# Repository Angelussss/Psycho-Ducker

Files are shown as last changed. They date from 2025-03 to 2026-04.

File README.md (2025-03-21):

# Psycho Ducker

Welcome to the Psycho Ducker, a 75% exploded keyboard project! This is a hot-swappable, compact, and efficient keyboard. Below, you'll find all the details you need to build and understand this project.

## Layout

The keyboard features a 75% exploded layout, offering a balance between functionality and compactness. The exploded design separates key clusters for a modern aesthetic and improved usability.

## Components

### Essentials

-   **MCU:** STM32F072CBT6.
    
-   **Switches:** Cherry MX style (supports both 3-pin and 5-pin switches).
    
-   **Keycaps:** Standard keycap set compatible with the Cherry MX stem.
    
-   **Diodes:** SOD-123.
    
-   **Hot-swap sockets:** Kailh are recommended.

### Optionals

-   **M2 screws** (to secure the PCB to the case or standoffs).
    
-   **M2 standoffs** (for added stability between the PCB and case).
    
-   **Stabilizers** (PCB-mounted, required for larger keys like the spacebar, enter, and shift).

## Required Tools

-   **Soldering iron**: Required for soldering pretty much the whole project.

- **heatgun**: Heavily hinted for soldering the micro. with a basic soldering iron is very hard.
    
-   **USB cable**: Required for connecting the keyboard to your computer. The PCB uses a usb type-C connector. Be sure to have at least one usable!

## Assembly Requirements

To assemble this keyboard, you'll need medium tin soldering skills, particularly for the micro.

## Notes

-   This keyboard's PCB is designed for hot-swapping switches, making possible to change the switches without de-soldering and re-soldering.
    
-   Firmware is powered by [QMK](https://qmk.fm/), a powerful and customizable open-source keyboard firmware.
    
-   This design has been tested thoroughly and functions reliably. However, as with any DIY project, minor adjustments may be needed based on your specific components.
    
-   Feel free to use this design for personal projects, but please do not edit or misuse it.
    
-in this design there are several types of cases you might wanna use. you can find the different materials and files in the "case" folder. The case is not necessary and is hands down the hardest part as it uses specific and expensive machinery, 

## Photos

-   **Finished Build:** ![fnished keyboard photo]
    
-   **Render:** ![pcb render] (https://github.com/Angelussss/Psycho-Ducker/blob/main/images/pcb_render.png)

## Contact

For any questions, feedback, or assistance, feel free to reach out via Telegram: @AngelusPSPS.

Thank you for exploring this project! Happy building and typing!

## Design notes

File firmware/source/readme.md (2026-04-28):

# psycho_ducker

![psycho_ducker]

*A 75% exploded keyboard*

* Keyboard Maintainer: [Angelo Perotti](https://github.com/Angelussss)
* Hardware Supported: psycho_ducker
* Hardware Availability: this project is opensource, you can build your own!

Make example for this keyboard (after setting up your build environment):

    make psycho_ducker:default

Flashing example for this keyboard:

    make psycho_ducker:default:flash

See the [build environment setup](https://docs.qmk.fm/#/getting_started_build_tools) and the [make instructions](https://docs.qmk.fm/#/getting_started_make_guide) for more information. Brand new to QMK? Start with our [Complete Newbs Guide](https://docs.qmk.fm/#/newbs).

## Bootloader

Enter the bootloader in 2 ways:

* **Physical reset button**: Briefly press the button on the top right of the PCB on boot 
* **Keycode in layout**: Press the key mapped to `QK_BOOT` if it is available

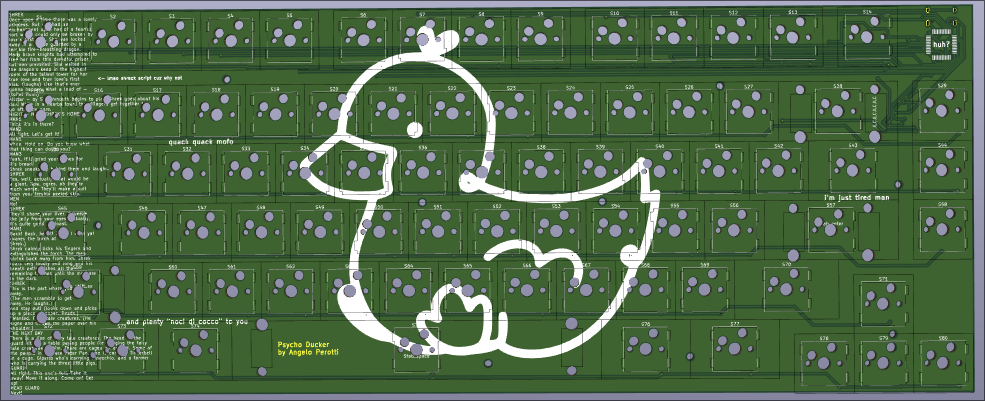
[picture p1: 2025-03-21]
images/pcb_render.png

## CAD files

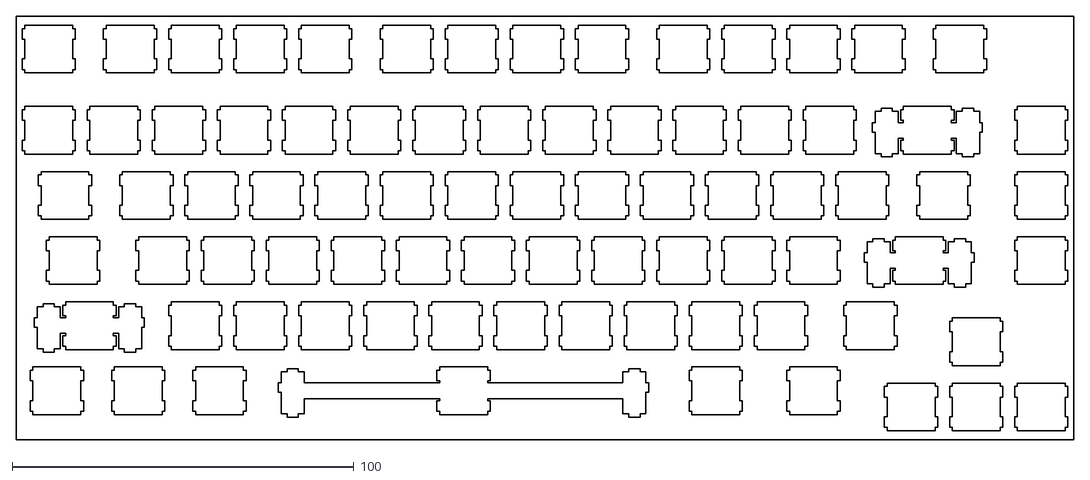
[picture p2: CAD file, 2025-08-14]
stuff/plate.dxf
309.6 x 123.8

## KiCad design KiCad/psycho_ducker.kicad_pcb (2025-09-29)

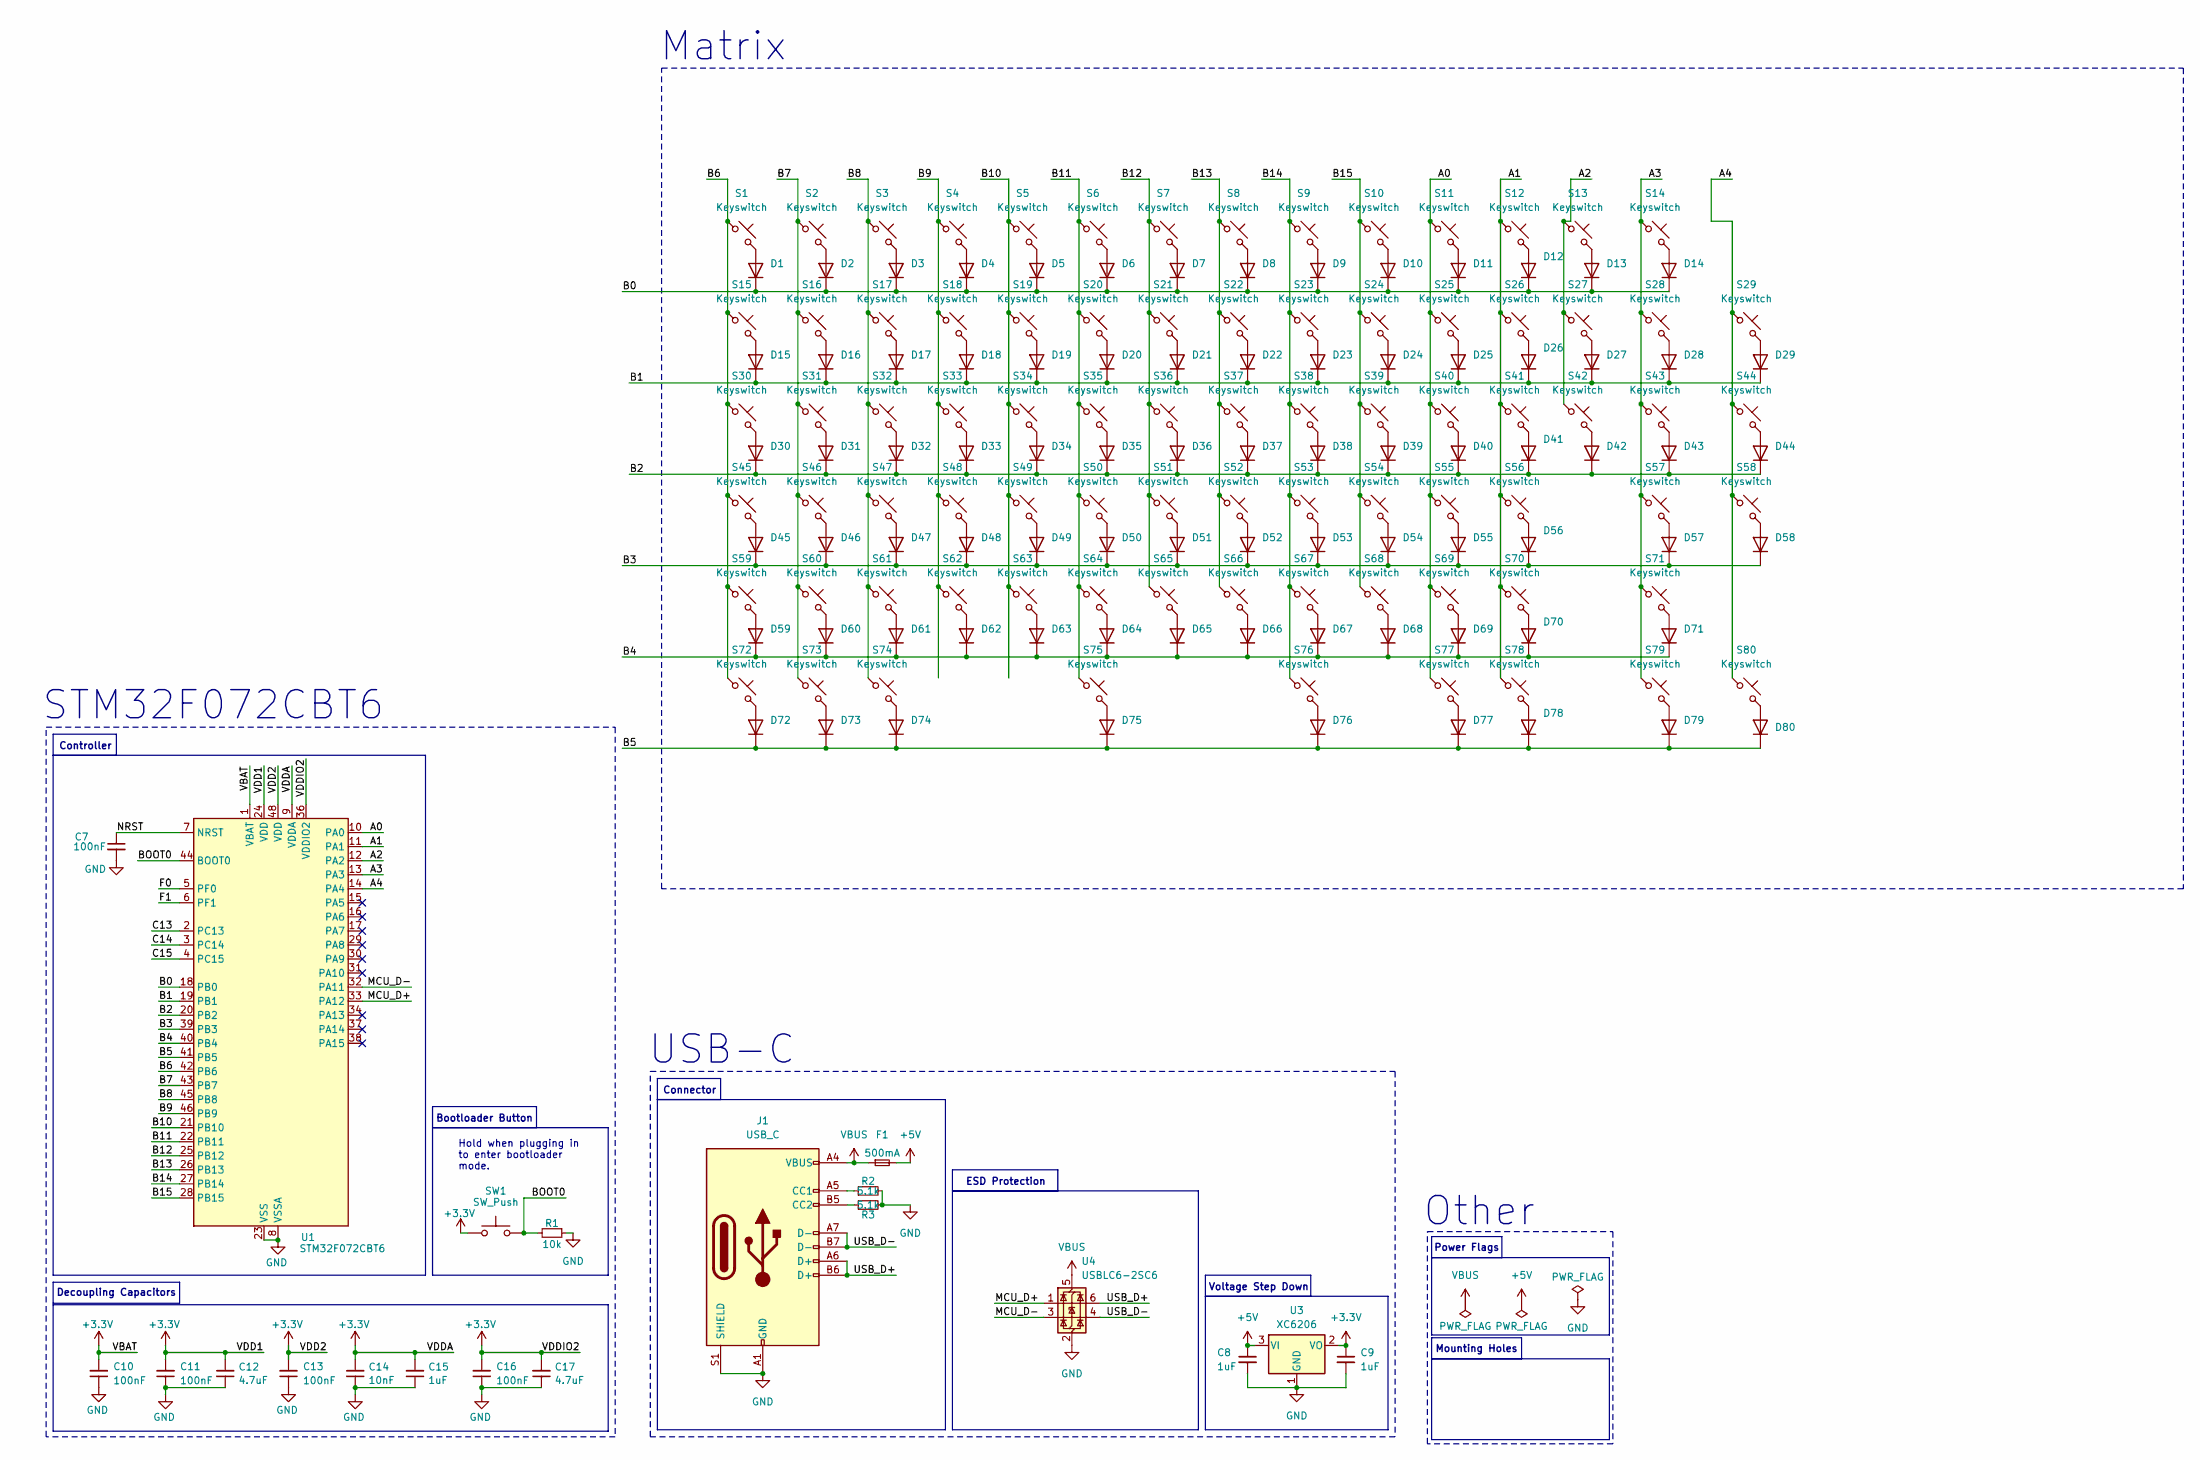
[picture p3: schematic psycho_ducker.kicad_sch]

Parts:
C7: 100nF; Capacitor_0402; LCSC C307331
C8, C9: 1uF; Capacitor_0402; LCSC C52923
C10, C11, C13, C16: 100nF; Capacitor_0402; MPN CL05B104KB54PNC; LCSC C307331
C12, C17: 4.7uF; Capacitor_0402; MPN CL05A475MP5NRNC; LCSC C23733
C14: 10nF; Capacitor_0402; MPN CL05B103KB5NNNC; LCSC C15195
C15: 1uF; Capacitor_0402; MPN CL05A105KA5NQNC; LCSC C52923
D1, D2, D3, D4, D5, D6, D7, D8, D9, D10, D11, D12, D13, D14, D15, D16, D17, D18, D19, D20, D21, D22, D23, D24, D25, D26, D27, D28, D29, D30, D31, D32, D33, D34, D35, D36, D37, D38, D39, D40, D41, D42, D43, D44, D45, D46, D47, D48, D49, D50, D51, D52, D53, D54, D55, D56, D57, D58, D59, D60, D61, D62, D63, D64, D65, D66, D67, D68, D69, D70, D71, D72, D73, D74, D75, D76, D77, D78, D79, D80: Diode; Diode_SOD-123
F1: 500mA; Fuse_0603; LCSC C210357
J1: USB_C; USB_C_HRO_TYPE-C-31-M-12; LCSC C165948
R1: 10k; R_0402_1005Metric; LCSC C25744
R2, R3: 5.1k; R_0402_1005Metric; LCSC C25905
S1, S2, S3, S4, S5, S6, S7, S8, S9, S10, S11, S12, S13, S14, S15, S16, S17, S18, S19, S20, S21, S22, S23, S24, S25, S26, S27, S29, S31, S32, S33, S34, S35, S36, S37, S38, S39, S40, S41, S42, S44, S46, S47, S48, S49, S50, S51, S52, S53, S54, S55, S56, S58, S60, S61, S62, S63, S64, S65, S66, S67, S68, S69, S71, S78, S79, S80: Keyswitch; Hotswap_MX_1.00u
S28: Keyswitch; Hotswap_MX_2.00u
S30, S43, S76, S77: Keyswitch; Hotswap_MX_1.50u
S45, S70: Keyswitch; Hotswap_MX_1.75u
S57, S59: Keyswitch; Hotswap_MX_2.25u
S72, S73, S74: Keyswitch; Hotswap_MX_1.25u
S75: Keyswitch; Hotswap_MX_6.25u
SW1: SW_Push; Button_TL3342; LCSC C115351
U1: STM32F072CBT6; Package_LQFP-48_7x7mm_P0.5; LCSC C81720
U3: XC6206; Voltage_SOT-23; LCSC C5446
U4: USBLC6-2SC6; ESD_SOT-23-6; LCSC C2827654

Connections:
+3.3V: C9.1, C10.2, C11.2, C12.2, C13.2, C14.2, C15.2, C16.2, C17.2, SW1.1, U1.1 (VBAT), U1.9 (VDDA), U1.24 (VDD), U1.36 (VDDIO2), U1.48 (VDD), U3.2 (VO)
+5V: C8.1, F1.2, U3.3 (VI)
/A0: S11.1, S25.1, S40.1, S55.1, S69.1, S77.1, U1.10 (PA0)
/A1: S12.1, S26.1, S41.1, S56.1, S70.1, S78.1, U1.11 (PA1)
/A2: S13.1, S27.1, S42.1, U1.12 (PA2)
/A3: S14.1, S28.1, S43.1, S57.1, S71.1, S79.1, U1.13 (PA3)
/A4: S29.1, S44.1, S58.1, S80.1, U1.14 (PA4)
/A5: U1.15 (PA5)
/A6: U1.16 (PA6)
/A7: U1.17 (PA7)
/A8: U1.29 (PA8)
/A9: U1.30 (PA9)
/A10: U1.31 (PA10)
/A13: U1.34 (PA13)
/A14: U1.37 (PA14)
/A15: U1.38 (PA15)
/B0: D1.1 (K), D2.1 (K), D3.1 (K), D4.1 (K), D5.1 (K), D6.1 (K), D7.1 (K), D8.1 (K), D9.1 (K), D10.1 (K), D11.1 (K), D12.1 (K), D13.1 (K), D14.1 (K), U1.18 (PB0)
/B1: D15.1 (K), D16.1 (K), D17.1 (K), D18.1 (K), D19.1 (K), D20.1 (K), D21.1 (K), D22.1 (K), D23.1 (K), D24.1 (K), D25.1 (K), D26.1 (K), D27.1 (K), D28.1 (K), D29.1 (K), U1.19 (PB1)
/B2: D30.1 (K), D31.1 (K), D32.1 (K), D33.1 (K), D34.1 (K), D35.1 (K), D36.1 (K), D37.1 (K), D38.1 (K), D39.1 (K), D40.1 (K), D41.1 (K), D42.1 (K), D43.1 (K), D44.1 (K), U1.20 (PB2)
/B3: D45.1 (K), D46.1 (K), D47.1 (K), D48.1 (K), D49.1 (K), D50.1 (K), D51.1 (K), D52.1 (K), D53.1 (K), D54.1 (K), D55.1 (K), D56.1 (K), D57.1 (K), D58.1 (K), U1.39 (PB3)
/B4: D59.1 (K), D60.1 (K), D61.1 (K), D62.1 (K), D63.1 (K), D64.1 (K), D65.1 (K), D66.1 (K), D67.1 (K), D68.1 (K), D69.1 (K), D70.1 (K), D71.1 (K), U1.40 (PB4)
/B5: D72.1 (K), D73.1 (K), D74.1 (K), D75.1 (K), D76.1 (K), D77.1 (K), D78.1 (K), D79.1 (K), D80.1 (K), U1.41 (PB5)
/B6: S1.1, S15.1, S30.1, S45.1, S59.1, S72.1, U1.42 (PB6)
/B7: S2.1, S16.1, S31.1, S46.1, S60.1, S73.1, U1.43 (PB7)
/B8: S3.1, S17.1, S32.1, S47.1, S61.1, S74.1, U1.45 (PB8)
/B9: S4.1, S18.1, S33.1, S48.1, S62.1, U1.46 (PB9)
/B10: S5.1, S19.1, S34.1, S49.1, S63.1, U1.21 (PB10)
/B11: S6.1, S20.1, S35.1, S50.1, S64.1, S75.1, U1.22 (PB11)
/B12: S7.1, S21.1, S36.1, S51.1, S65.1, U1.25 (PB12)
/B13: S8.1, S22.1, S37.1, S52.1, S66.1, U1.26 (PB13)
/B14: S9.1, S23.1, S38.1, S53.1, S67.1, S76.1, U1.27 (PB14)
/B15: S10.1, S24.1, S39.1, S54.1, S68.1, U1.28 (PB15)
/BOOT0: R1.2, SW1.2, U1.44 (BOOT0)
/C13: U1.2 (PC13)
/C14: U1.3 (PC14)
/C15: U1.4 (PC15)
/F0: U1.5 (PF0)
/F1: U1.6 (PF1)
/MCU_D+: U1.33 (PA12), U4.1 (I/O1)
/MCU_D-: U1.32 (PA11), U4.3 (I/O2)
/NRST: C7.1, U1.7 (NRST)
/USB_D+: J1.A6 (D+), J1.B6 (D+), U4.6 (I/O1)
/USB_D-: J1.A7 (D-), J1.B7 (D-), U4.4 (I/O2)
GND: C7.2, C8.2, C9.2, C10.1, C11.1, C12.1, C13.1, C14.1, C15.1, C16.1, C17.1, J1.A1 (GND), J1.A12 (GND), J1.B1 (GND), J1.B12 (GND), J1.S1 (SHIELD), R1.1, R2.2, R3.2, U1.8 (VSSA), U1.23 (VSS), U1.35 (VSS), U1.47 (VSS), U3.1 (GND), U4.2 (GND)
unnamed: D1.2 (A), S1.2
unnamed: D2.2 (A), S2.2
unnamed: D3.2 (A), S3.2
unnamed: D4.2 (A), S4.2
unnamed: D5.2 (A), S5.2
unnamed: D6.2 (A), S6.2
unnamed: D7.2 (A), S7.2
unnamed: D8.2 (A), S8.2
unnamed: D9.2 (A), S9.2
unnamed: D10.2 (A), S10.2
unnamed: D11.2 (A), S11.2
unnamed: D12.2 (A), S12.2
unnamed: D13.2 (A), S13.2
unnamed: D14.2 (A), S14.2
unnamed: D15.2 (A), S15.2
unnamed: D16.2 (A), S16.2
unnamed: D17.2 (A), S17.2
unnamed: D18.2 (A), S18.2
unnamed: D19.2 (A), S19.2
unnamed: D20.2 (A), S20.2
unnamed: D21.2 (A), S21.2
unnamed: D22.2 (A), S22.2
unnamed: D23.2 (A), S23.2
unnamed: D24.2 (A), S24.2
unnamed: D25.2 (A), S25.2
unnamed: D26.2 (A), S26.2
unnamed: D27.2 (A), S27.2
unnamed: D28.2 (A), S28.2
unnamed: D29.2 (A), S29.2
unnamed: D30.2 (A), S30.2
unnamed: D31.2 (A), S31.2
unnamed: D32.2 (A), S32.2
unnamed: D33.2 (A), S33.2
unnamed: D34.2 (A), S34.2
unnamed: D35.2 (A), S35.2
unnamed: D36.2 (A), S36.2
unnamed: D37.2 (A), S37.2
unnamed: D38.2 (A), S38.2
unnamed: D39.2 (A), S39.2
unnamed: D40.2 (A), S40.2
unnamed: D41.2 (A), S41.2
unnamed: D42.2 (A), S42.2
unnamed: D43.2 (A), S43.2
unnamed: D44.2 (A), S44.2
unnamed: D45.2 (A), S45.2
unnamed: D46.2 (A), S46.2
unnamed: D47.2 (A), S47.2
unnamed: D48.2 (A), S48.2
unnamed: D49.2 (A), S49.2
unnamed: D50.2 (A), S50.2
unnamed: D51.2 (A), S51.2
unnamed: D52.2 (A), S52.2
unnamed: D53.2 (A), S53.2
unnamed: D54.2 (A), S54.2
unnamed: D55.2 (A), S55.2
unnamed: D56.2 (A), S56.2
unnamed: D57.2 (A), S57.2
unnamed: D58.2 (A), S58.2
unnamed: D59.2 (A), S59.2
unnamed: D60.2 (A), S60.2
unnamed: D61.2 (A), S61.2
unnamed: D62.2 (A), S62.2
unnamed: D63.2 (A), S63.2
unnamed: D64.2 (A), S64.2
unnamed: D65.2 (A), S65.2
unnamed: D66.2 (A), S66.2
unnamed: D67.2 (A), S67.2
unnamed: D68.2 (A), S68.2
unnamed: D69.2 (A), S69.2
unnamed: D70.2 (A), S70.2
unnamed: D71.2 (A), S71.2
unnamed: D72.2 (A), S72.2
unnamed: D73.2 (A), S73.2
unnamed: D74.2 (A), S74.2
unnamed: D75.2 (A), S75.2
unnamed: D76.2 (A), S76.2
unnamed: D77.2 (A), S77.2
unnamed: D78.2 (A), S78.2
unnamed: D79.2 (A), S79.2
unnamed: D80.2 (A), S80.2
unnamed: J1.A5 (CC1), R2.1
unnamed: J1.B5 (CC2), R3.1
VBUS: F1.1, J1.A4 (VBUS), J1.A9 (VBUS), J1.B4 (VBUS), J1.B9 (VBUS), U4.5 (VBUS)

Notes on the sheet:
Hold when plugging in to enter bootloader mode.
STM32F072CBT6
USB-C
Mounting Holes
Decoupling Capacitors
Controller
ESD Protection
Power Flags
Voltage Step Down
Other
Bootloader Button
Matrix
Connector

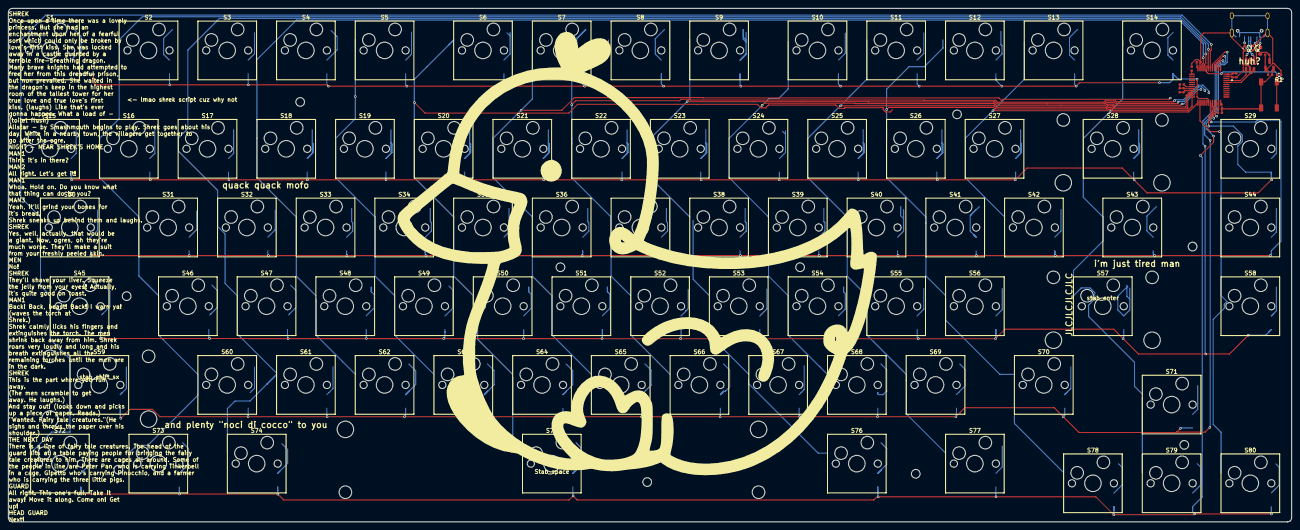
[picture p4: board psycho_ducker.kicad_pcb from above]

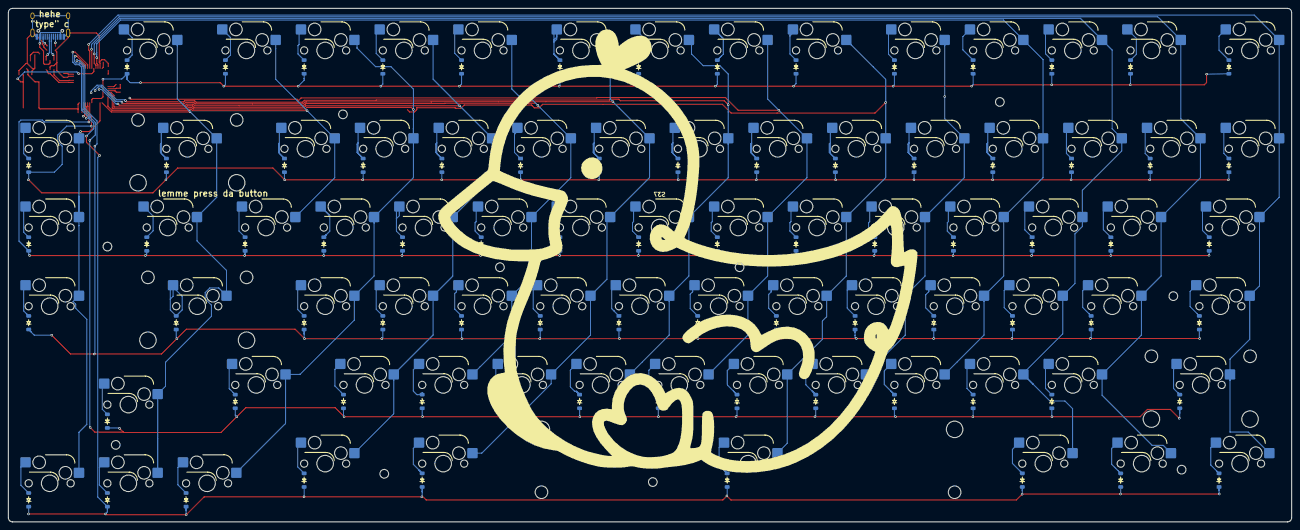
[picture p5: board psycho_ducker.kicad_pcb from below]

Board: 2 copper layers, 310.6 x 124.3 mm, 186 parts (82 on the bottom side), 113 nets.

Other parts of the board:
Stab_space: Stabilizer_MX_6.25u
backduck: LOGO
frontduck: LOGO
stab_backspace: Stabilizer_MX_2.00u
stab_enter: Stabilizer_MX_2.00u
stab_shift_sx: Stabilizer_MX_2.00u

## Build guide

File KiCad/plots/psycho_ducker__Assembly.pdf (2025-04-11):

<- | lmao shreck script cuz why not | huh?
and | plenty "noci | di cocco" to you | JLCJLCJLCJLC
quack | quack mofo
SHREK Once upon a time there was a lovely princess. | But she had an
enchantment | upon her of a fearful sort which could only be broken by

love's first kiss. She was locked away in a castle guarded by a
terrible | fire-breathing | dragon. Many brave knights | had attempted | to
free her from this dreadful | prison, but non prevailed. | She waited in
the dragon's | keep in the highest room of the tallest | tower for her
true love and true love's first kiss. (laughs) | Like that's | ever gonna happen. What a load of -
(toilet | flush) Allstar - by Smashmouth | begins to play. Shrek goes about his day. While in a nearby town, the villagers | get together | to

go after the ogre. NIGHT - NEAR SHREK'S HOME MAN1 Think it's in there? MAN2 All right. Let's get it! MAN1 Whoa. Hold on. Do you know what

that thing can do to you? MAN3 Yeah, it'll grind your bones for

it's bread. Shrek sneaks up behind them and laughs. SHREK

Yes, well, actually, that would be
a giant. Now, ogres, oh they're much worse. They'll make a suit

from your freshly peeled skin. MEN

No! SHREK

They'll shave your liver. Squeeze the jelly from your eyes! Actually,
it's quite good on toast. MAN1 Back! Back, beast! Back! I warn ya! (waves the torch at Shrek.) Shrek calmly | licks his fingers | and
extinguishes | the torch. The men
shrink back away from him. Shrek
roars very loudly and long and his breath extinguishes | all the
remaining | torches | until the men are
in the dark. SHREK

This is the part where you run away. (The men scramble to get away. He laughs.) And stay out! (looks down and picks up a piece of paper. Reads.) "Wanted. Fairy tale creatures."(He

sighs and throws the paper over his
shoulder.) THE NEXT DAY
There is a line of fairy tale creatures. | The head of the
guard sits at a table paying people for bringing | the fairy
tale creatures | to him. There are cages all around. Some of
the people in line are Peter Pan, who is carrying | Tinkerbell
in a cage, Gipetto who's carrying | Pinocchio, | and a farmer who is carrying | the three little | pigs. GUARD

All right. This one's full. Take it away! Move it along. Come on! Get up! HEAD GUARD

Next!

## i'm just tired man JLCJLCJLCJLC

S77

S18 S47 S15 | S27 S64 | S65 | S70 S26 S67 | S42 S19 | S29 S14 S51 S33 | S57 S12 S21 | S39 S45 | S68 S31 | Stab_space S74 | S53 | S24 S7 | S69 S50 | S11 S55 S60

S1

stab_enter S75 S62 | S79 S41 S22 | S66 S32 | S38 S49 | S52 | S54 S30 | S76
S5 | S63
S3 | S4 | S9 | S25 | S80 S73 | S56 S35 S46 | S78 | S43 S59 | S34 S16 S72 | S58 S10 S36 S61
S6 | S44 S48 S17 | S20 | S23 | S40

stab_shift_sx

S2 | S8 | S13 | S28 | S71
1 | 2 | 3 | 4 | 5 | 6 | 7 | 8 | 9 | 10 | 11 | 12 | 13 | 14 | 15 | 16
1 | 2 | 3 | 4 | 5 | 6 | 7 | 8 | 9 | 10 | 11 | 12 | 13 | 14 | 15 | 16

A

BC

D

E

FG

H

## IJK

A

BC

D

E

FG

H

IJK Date: 9/11/2024 KiCad E.D.A. 8.0.6 Size: A1 | Rev: 1.0.1
Id: 1/1 Title: psycho_ducker File: psycho_ducker.kicad_pcb Sheet: Black And White TOP Angelo Perotti Board2Pdf: | Black And White TOP - Page 1/2

Keyswitch S77

Keyswitch S18 Keyswitch S47 | Keyswitch S27 Keyswitch S15 | Keyswitch S70 Keyswitch S64 | Keyswitch S65 | Keyswitch S26 Keyswitch S67 | Keyswitch S42 Keyswitch S19 | Keyswitch S29 Keyswitch S14 Keyswitch S51 Keyswitch S33 | Keyswitch S57 Keyswitch S12 Keyswitch S21 | Keyswitch S39 Keyswitch S45 | Keyswitch S68 Keyswitch S31 | Stabilizer_MX_6.25u Stab_space Keyswitch S74 | Keyswitch S53Keyswitch S24 Keyswitch S7 | Keyswitch S69 Keyswitch S50 | Keyswitch S11 Keyswitch S55 Keyswitch S60
Keyswitch S1 | Stabilizer_MX_2.00u
stab_enter Keyswitch S75 Keyswitch S62 | Keyswitch S79 Keyswitch S41 Keyswitch S22 | Keyswitch S66Keyswitch S38 Keyswitch S32 | Keyswitch S49 | Keyswitch S54 Keyswitch S37Keyswitch S52 Keyswitch S30 | Keyswitch S76
Keyswitch S5 | Keyswitch S63
Keyswitch S3 | Keyswitch S4 | Keyswitch S9 | Keyswitch S25 | Keyswitch S80 Keyswitch S73 | Keyswitch S56 Keyswitch S35 Keyswitch S46 | Keyswitch S78 | Keyswitch S43 Keyswitch S59 | Keyswitch S34 Keyswitch S16 Keyswitch S72 | Keyswitch S58 Keyswitch S10 Keyswitch S36 Keyswitch S61
Keyswitch S6 | Keyswitch S44 Keyswitch S48 | Keyswitch S20 | Keyswitch S23 Keyswitch S17 | Keyswitch S40 Stabilizer_MX_2.00u
stab_shift_sx | Stabilizer_MX_2.00u
stab_backspace Keyswitch S13 Keyswitch S8 Keyswitch S2 | Keyswitch S28 | Keyswitch S71

1 | 2 | 3 | 4 | 5 | 6 | 7 | 8 | 9 | 10 | 11 | 12 | 13 | 14 | 15 | 16

A

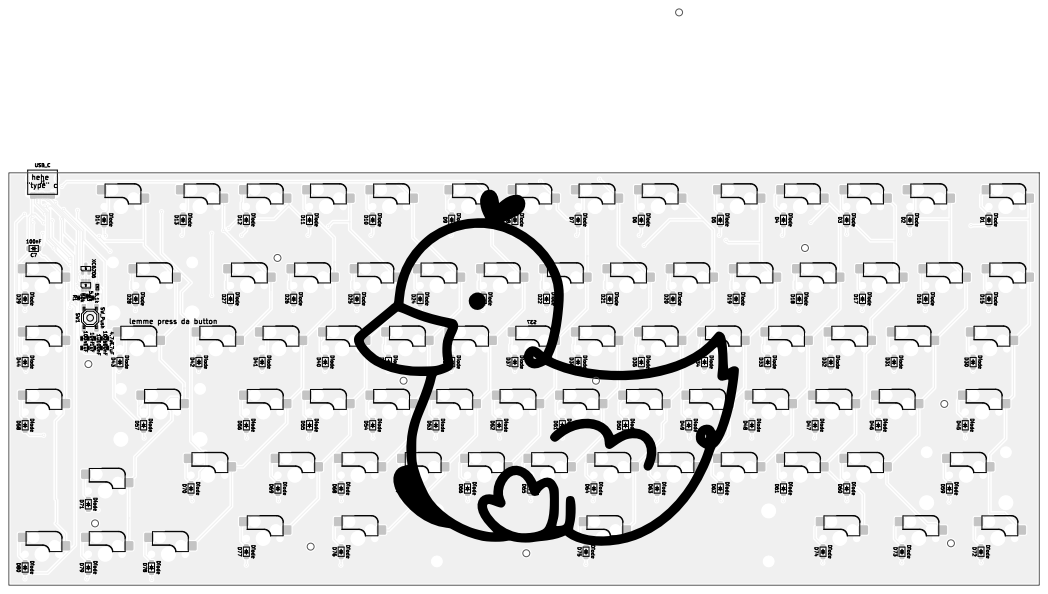
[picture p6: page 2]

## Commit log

2025-02-24 added v1.0.0 gerber files
2025-03-21 feat: added pcb render
2025-04-11 feat: added interactive bom
2025-04-11 fix: c7 footprint, jlc code repetition, shrek typo and added duck
    [psycho_ducker.kicad_sch]
2025-08-13 feat: started pcb front plate case
    [Psycho-Ducker-case.kicad_pcb, Psycho-Ducker-case.kicad_sch]
2025-08-14 feat: added front plate dxf base file
    [plate.dxf]
2025-08-15 feat: added front plate pcb
    [Psycho-Ducker-case.kicad_pcb, Psycho-Ducker-case.kicad_sch]
2025-08-15 feat: added backplate
    [backplate.kicad_pcb, backplate.kicad_sch]
2025-08-15 fix: useless files
    [Psycho-Ducker-case.kicad_pcb, Psycho-Ducker-case.kicad_sch]
2025-08-15 fix: backplate filling
    [backplate.kicad_pcb]
2025-08-16 feat: backplate now has mounting holes compatible with the main pcb
    [backplate.kicad_pcb]
2025-08-17 feat: changed backplate pattern
    [backplate.kicad_pcb]
2025-08-17 feat: added rubber feet placement
    [backplate.kicad_pcb]
2025-08-17 fix: removed sch file as it is useless
    [backplate.kicad_sch]
2025-08-17 feat: added _style_ to the pcb
    [backplate.kicad_pcb]
2025-08-17 feat: added Bo Burnham cit
    [backplate.kicad_pcb]
2025-08-17 feat: added JLC PCB required text
    [backplate.kicad_pcb]
2025-08-17 feat: added rounded corners
    [Psycho-Ducker-case.kicad_pcb]
2025-08-17 feat: added mounting holes
    [Psycho-Ducker-case.kicad_pcb]
2025-08-18 fix: minor fixes
    [backplate.kicad_pcb]
2025-08-18 fix: removed useless folder
    [backplate.kicad_pcb]
2025-08-18 feat: added latest production file
    [designators.csv]
2025-08-18 fix: moved backplate folder content into the backplate folder before said backplate folder, making the backplate folder unique and not a redundant backplate folder just like the backplate folder prio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
    [backplate.kicad_pcb]
2025-08-19 fix: removed useless file
    [Psycho-Ducker-case.kicad_sch]
2025-08-21 fix: renamed folders
    [Psycho-Ducker-case.kicad_pcb, backplate.kicad_pcb, designators.csv]
2025-08-26 fix: file placement
    [Psycho-Ducker-case.kicad_pcb, backplate.kicad_pcb, designators.csv]
2025-09-28 fix: removed MCU and various IC for a start=over routing journey
    [psycho_ducker.kicad_pcb]
2025-09-28 fix: removed holes from schematic
    [psycho_ducker.kicad_sch]
2025-09-29 fix: disconnected unused pins
    [psycho_ducker.kicad_sch]
2025-09-29 feat: updated routing
    [psycho_ducker.kicad_pcb]
2025-09-29 feat: added 3V3 and GND planes
2026-01-26 feat: added WS2812B to the pcb
    [psycho_ducker.kicad_sch]
2026-01-26 fix: mounting holes placement
2026-03-06 fix: added border for plate mount
    [Psycho-Ducker-case.kicad_pcb, designators.csv]
